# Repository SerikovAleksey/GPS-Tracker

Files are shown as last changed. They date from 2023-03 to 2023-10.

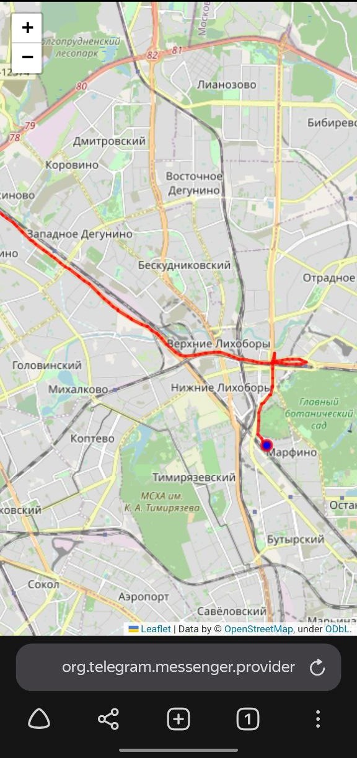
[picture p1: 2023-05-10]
Инструкция/7.jpg

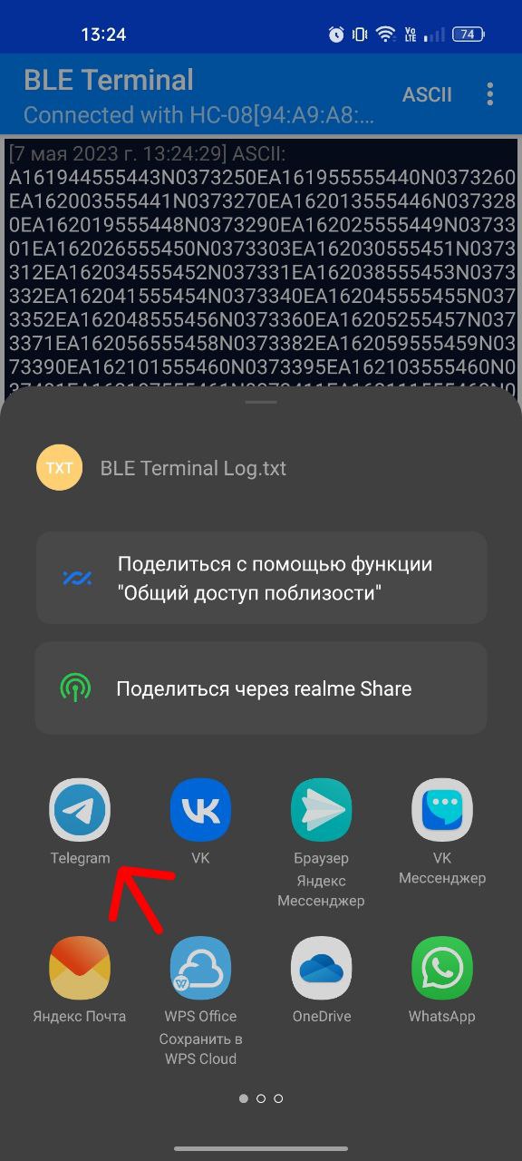
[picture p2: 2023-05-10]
Инструкция/3.jpg

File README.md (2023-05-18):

# GPS-Tracker
Репозиторий с проектом по курсу ПФТиКМИ студентов 2 курса ФАКТ:
- [Бунакова Егора](https://vk.com/egobun)
- [Серикова Алексея](https://vk.com/lehand_man)
- [Потапова Сергея](https://vk.com/keys619)

Данный проект основан на давнем желание Егора о создании своими руками GPS устройствва, с помощью которого можно посмотреть свой путь во время активного времяпрепровождения в походе, на рыбалке, на охоте и т.п.
Данный девайс должен удовлетворять нескольким требованием таким как:
- интуитивное управление
- быстрая передача данных на телефон
- долгое время работы без подзаряда

Ознакомиться с презентацией защиты плана можно [тут](https://github.com/SerikovAleksey/GPS-Tracer/blob/main/GPS%20Tracer.pptx).

А также получить подробную версию плана можно [тут](https://github.com/SerikovAleksey/GPS-Tracer/blob/main/PLAN.md).

Презентацию с защитой макета можно посмотреть [тут](https://github.com/SerikovAleksey/GPS-Tracker/blob/main/maket_defence.pptx).

Инструкцию по использованию GPS TRACKER можно посмотреть [тут](https://github.com/SerikovAleksey/GPS-Tracker/blob/main/Инструкция/Инструкция.pdf).

Протоколы испытаний можно посмотреть [тут](https://github.com/SerikovAleksey/GPS-Tracker/tree/main/Испытания).

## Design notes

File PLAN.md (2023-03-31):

# План проекта GPS Tracer 

1. Проблема 
2. Вариант решения
3. Компоненты 
4. Задачи

## Проблема 

Основным устройством, которое есть у всех, является телефон, на который можно 
установить различные приложения для отслеживания своего местоположения, но зачастую это 
становится невозможным ввиду погодных условий и других обстоятельств. Поэтому есть 
портативные устройства, выполняющие такие же задачи, но в суровых условиях. И основная 
проблема данных девайсов в их цене, она колеблется от 5 до нескольких десятков тыс. 
рублей.

## Вариант решения

С нашей стороны мы можем создать устройство способное выполнять функцию получения
данных со спутников, но за гораздо меньшую стоимость. Еще нужно для телефона написать 
приложение, где можно уже посмотреть на карте трек пройденного маршрута.

## Необходимые компоненты

| Название | Стоимость, ₽ |
|---|---|
| Приёмник GPS | ~350 |
| Модуль Bluetooth  | ~350 |
| Модуль зарядки аккумулятора| ~100|
| STM32F103C8T6 | ~150 |
| Кнопки | ~100 |
| Аккумулятор | ~500 |
| ИТОГО | ~1500 |

Цены на модули взяты с сайта [Амперо](https://ampero.ru/)

## Задачи

Перед нами встает ряд нескольких задач, которые нужно решить:
- Собрать макет устройства, т.е спаять все компоненты, и проверить его работоспособность.
- Разработать и распечатать на 3D принтере корпус.
- Создать приложение на телефон, в котором с помощью Bluetooth можно получить данные 
с устройства и визуализировать трек на карте.
- Написать инструкцию по эксплуатации.
- Провести независимые тестирования.

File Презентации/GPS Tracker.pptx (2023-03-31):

## GPS TracKer

Авторы:
Бунаков Егор
Потапов сергей
Сериков алексей

## Проблема

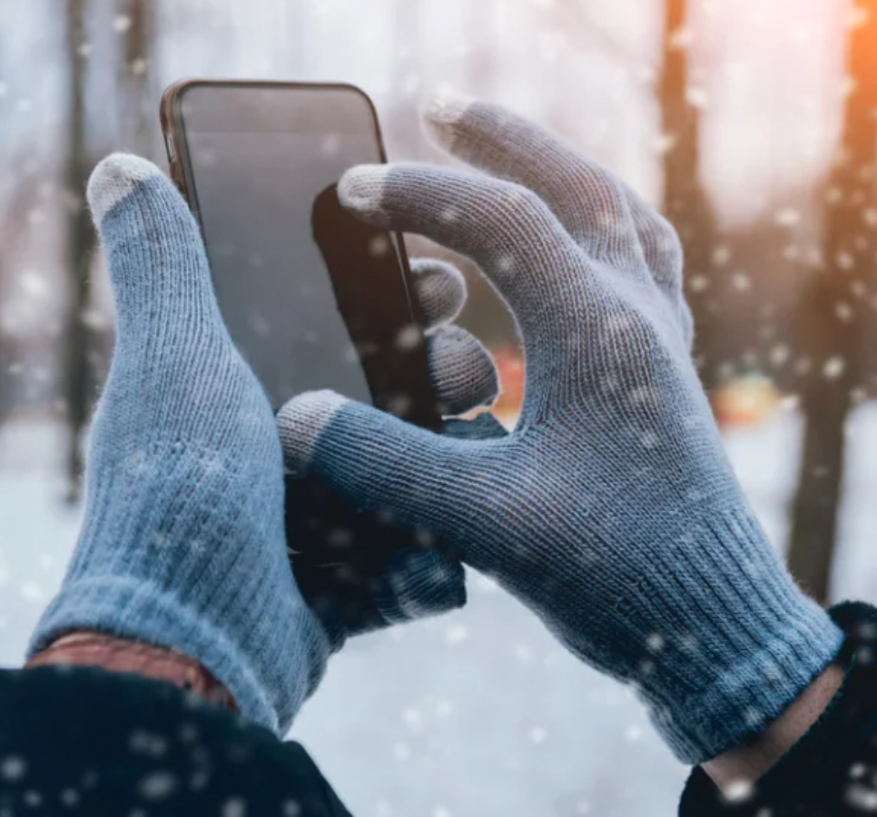
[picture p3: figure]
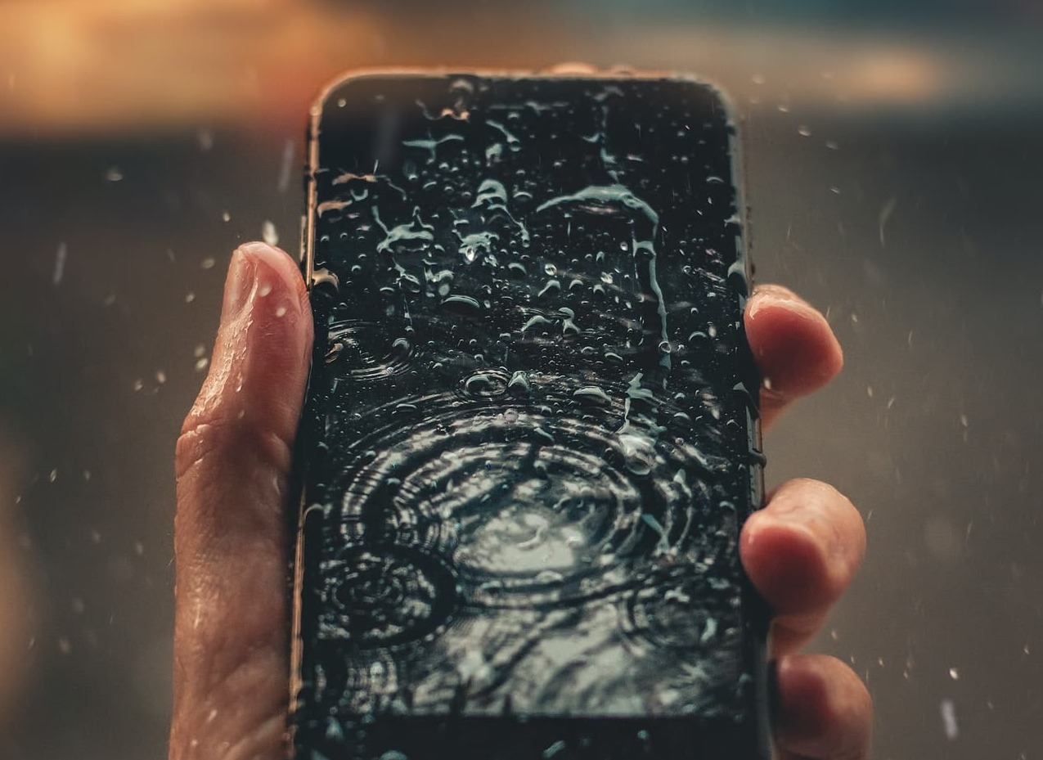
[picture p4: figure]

- Использование телефона в суровых условиях.
- Потеря связи.
- Дорогие аналоги.

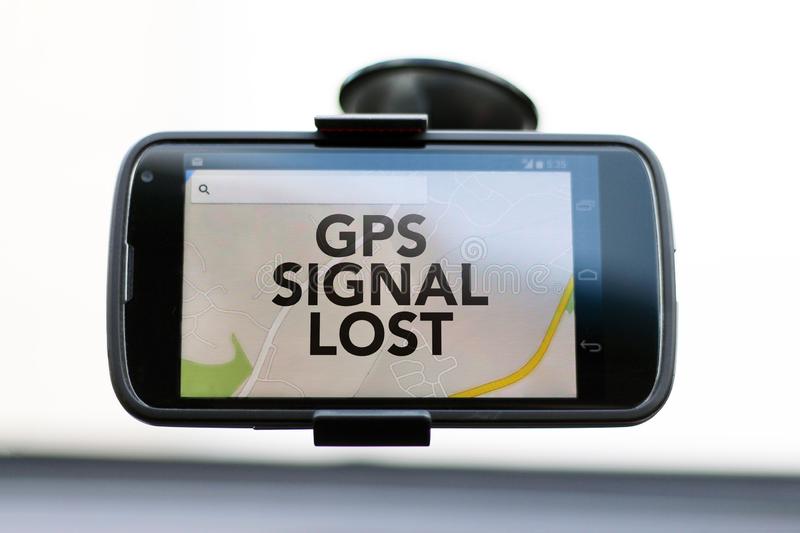
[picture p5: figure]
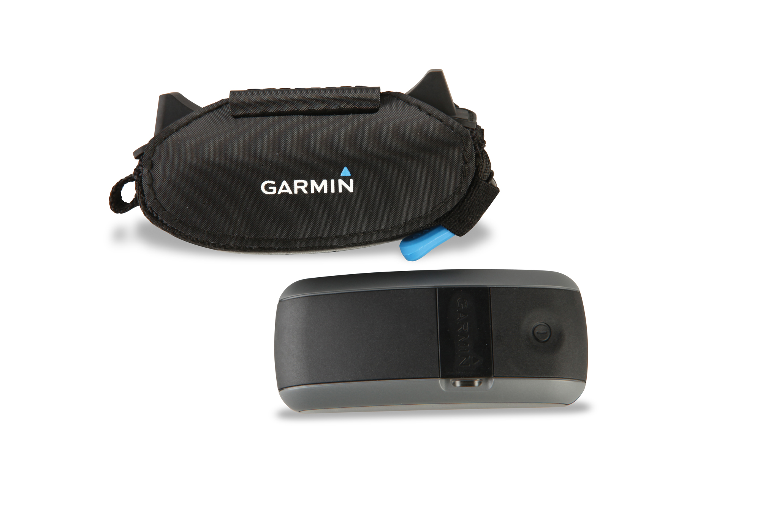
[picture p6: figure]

## Вариант решения

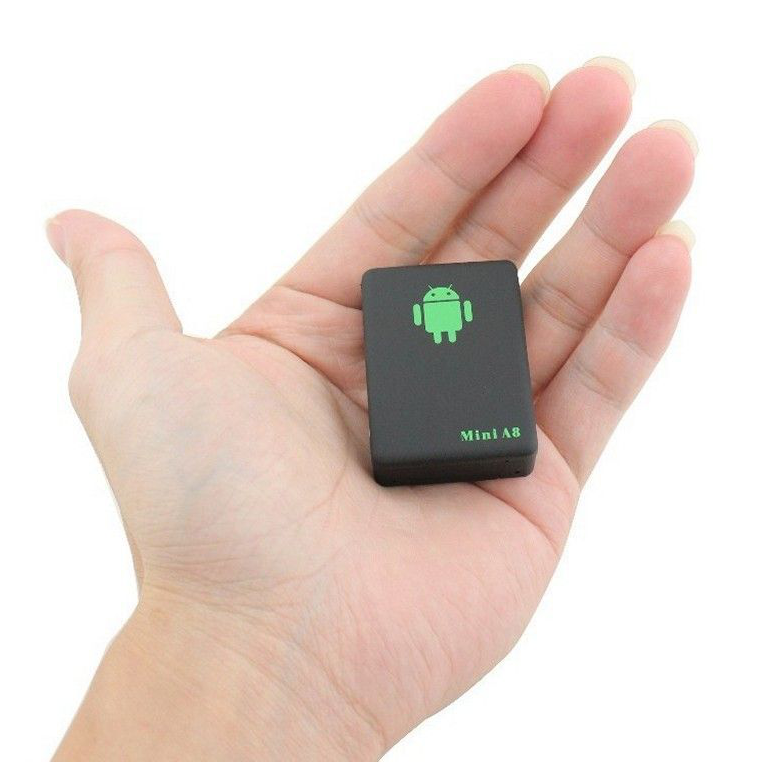
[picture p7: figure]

- Простое, компактное устройство.
- Надежные компоненты.
- Интуитивное использование.

## Задачи

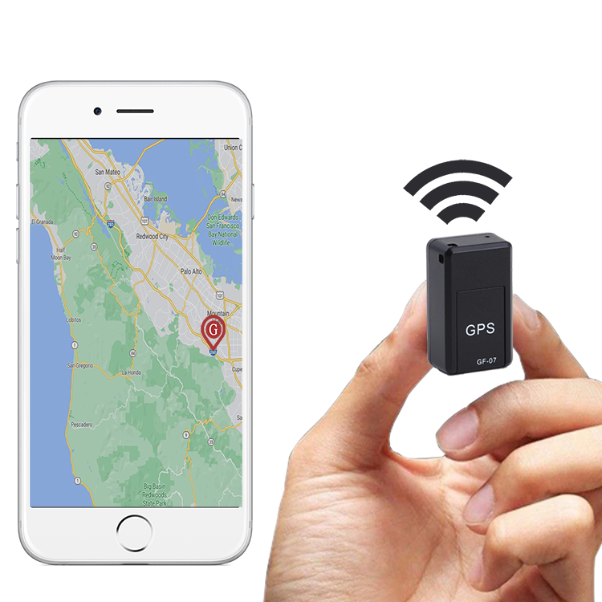
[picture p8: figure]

- Создать автономное GPS устройство.
- Сделать приложение на телефон.

## Начальные условия

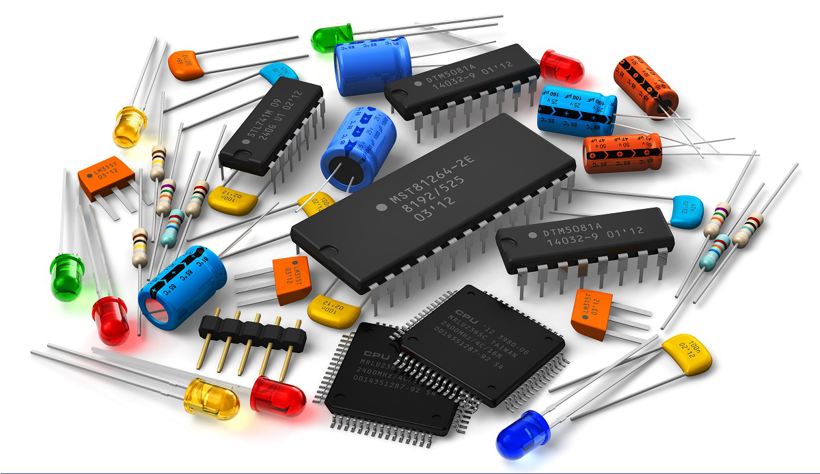
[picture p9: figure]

- РТ компоненты.
- 3D печать.
- Паяльные принадлежности.

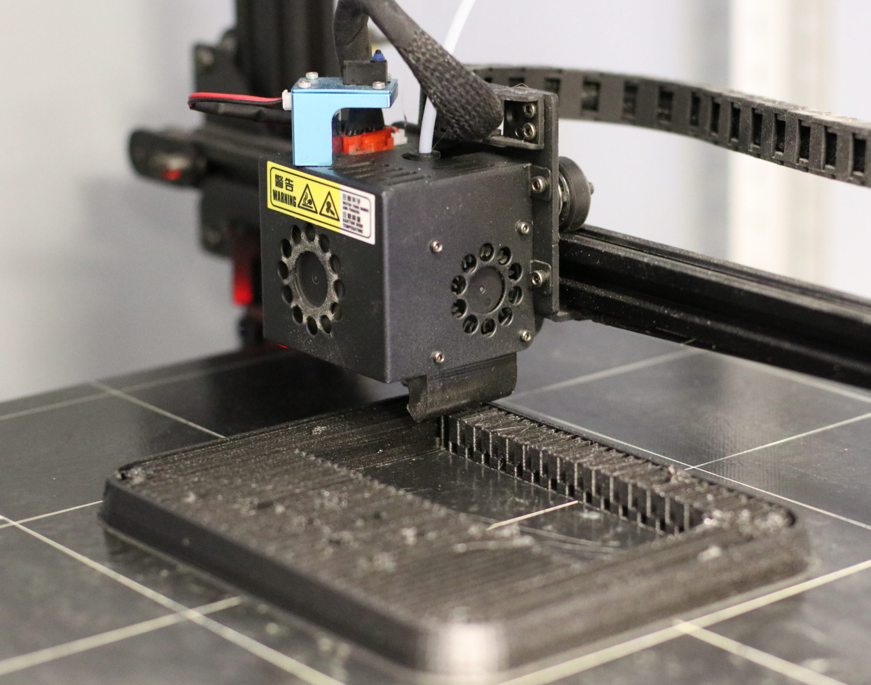
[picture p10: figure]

## Компоненты

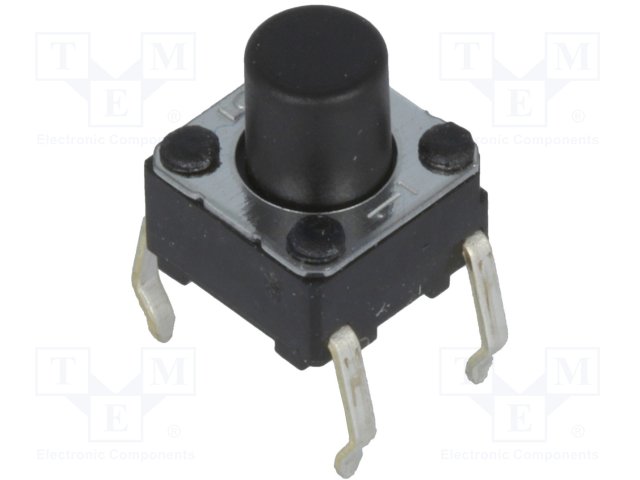
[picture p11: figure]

- STM32F103C8T6.
- GPS модуль.
- Bluetooth модуль.
- Кнопки
- Аккумулятор.

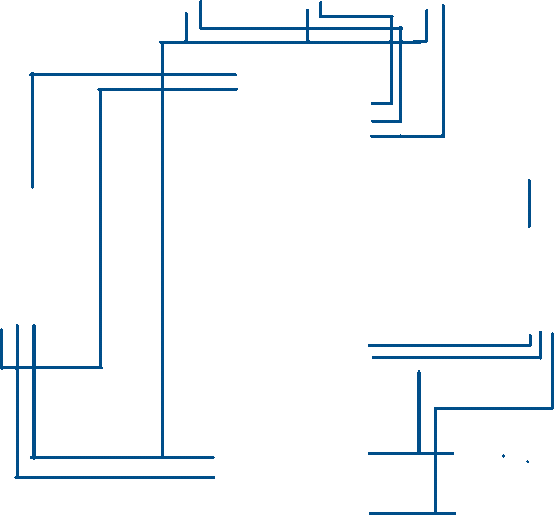
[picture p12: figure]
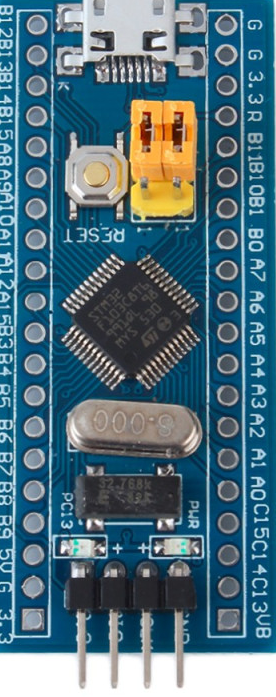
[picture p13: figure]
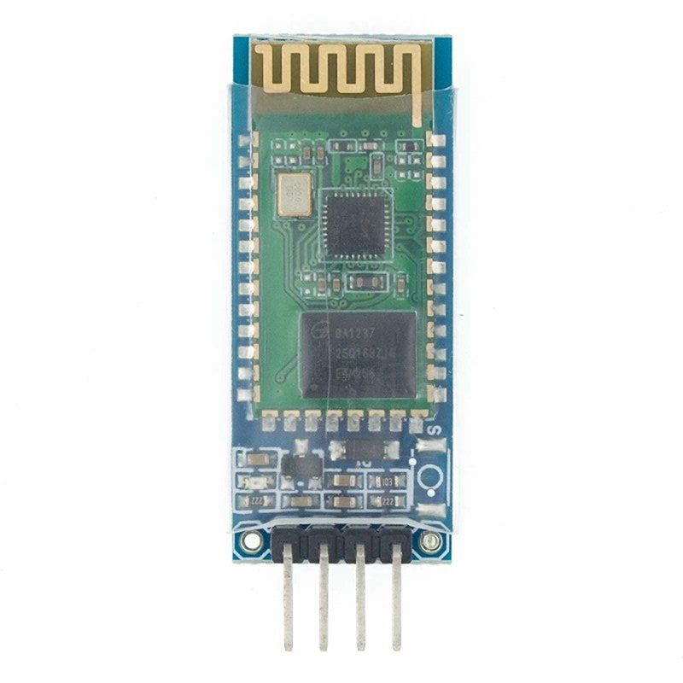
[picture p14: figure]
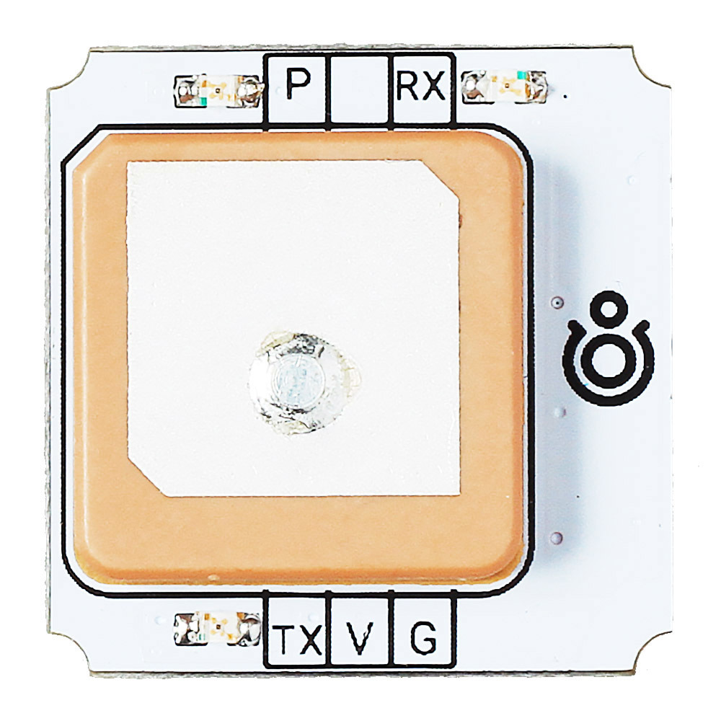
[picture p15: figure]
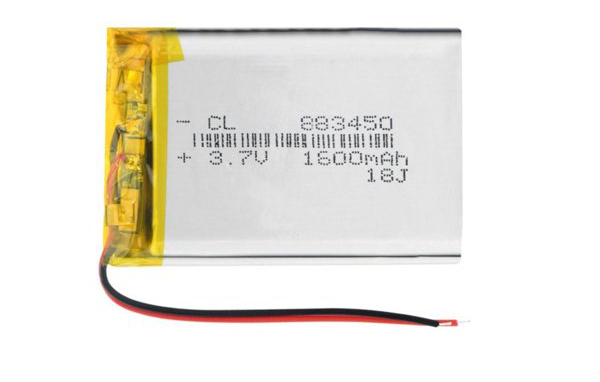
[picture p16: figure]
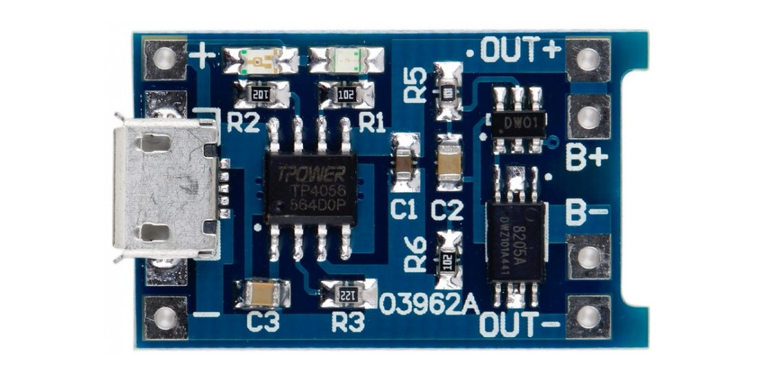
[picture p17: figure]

## Контакты

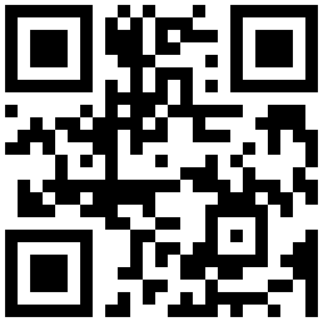
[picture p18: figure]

- Telegram канал нашего проекта

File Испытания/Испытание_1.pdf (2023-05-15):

Федеральное государственное автономное образовательное учреждение высшего образования «Московский физико-технический институт (национальный исследовательский университет)»

________________________________________________________________________________

### ПРОТОКОЛ ИСПЫТАНИЙ

№ 001/23

от «1» мая 2023 г.

1. Объект испытания: GPS TRACKER
2. Цель испытания: проверка соответствия объекта испытания требованиям пунктов 2.2, 2.3, 2.5 технического задания:

-2.2(Инструментальная погрешность навигационных определений),

-2.3(Время получения первых навигационных определений),

-2.5(Потребляемая мощность).

3. Дата начала испытания: 2 мая 2023 г.
4. Дата окончания испытания: 4 мая 2023 г.
5. Место проведения испытания: г. Москва

6. Результаты испытания
Наименование параметра | Единицы измерения | Методика испытаний | Требования к параметру | Измеренное значение
Инструментальная погрешность навигационных определений | М(метр) | Запись трека в течении 2 часов | ± 5м | ± 8м
Время получения первых навигационных определений | С(секунда) | Фиксирование времени получения навигационных определений | 5с (горячий старт) 35с (теплый старт) 50с (холодный старт) | 4с (горячий старт) 33с (теплый старт) 45с (холодный старт)
Потребляемая мощность | Вт (Ватт) | Фиксирование времени работы устройства | 0.2Вт | 0.26Вт
7. Замечания и рекомендации:

Погрешность навигационных определений выше, чем заявлена, в городе точность невысокая.

При холодном старте необходимо стоять на месте, иначе время получения первых навигационных определений выше.

Время работы устройства меньше заявленного.

8. Выводы:
8.1. Объект испытания GPS TRACKER соответствует требованиям пункта 2.3 технического задания.
8.2. Объект испытания GPS TRACKER не соответствует требованиям пунктов 2.2 и 2.5 технического задания.

Испытание проводили:

Должность | И.О. Фамилия | Подпись
Тестировщик | А.М. Галактионова

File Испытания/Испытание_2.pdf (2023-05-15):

Федеральное государственное автономное образовательное учреждение высшего образования «Московский физико-технический институт (национальный исследовательский университет)»

________________________________________________________________________________

### ПРОТОКОЛ ИСПЫТАНИЙ

№ 002/23

от «10» мая 2023 г.

1. Объект испытания: GPS TRACKER
2. Цель испытания: проверка соответствия объекта испытания требованиям пунктов 2.2, 2.3, 2.5 технического задания:

-2.2(Инструментальная погрешность навигационных определений),

-2.3(Время получения первых навигационных определений),

-2.5(Потребляемая мощность).

3. Дата начала испытания: 11 мая 2023 г.
4. Дата окончания испытания: 12 мая 2023 г.
5. Место проведения испытания: г. Москва

6. Результаты испытания
Наименование параметра | Единицы измерения | Методика испытаний | Требования к параметру | Измеренное значение
Инструментальная погрешность навигационных определений | М(метр) | Запись трека в течении 2 часов | ± 8м | ± 7м
Время получения первых навигационных определений | С(секунда) | Фиксирование времени получения навигационных определений | 5с (горячий старт) 35с (теплый старт) 50с (холодный старт) | 3с (горячий старт) 31с (теплый старт) 49с (холодный старт)
Потребляемая мощность | Вт (Ватт) | Фиксирование времени работы устройства | 0.26Вт | 0.24Вт
7. Замечания и рекомендации:

Точность полученных данных лежит в пределах погрешности.

Мощность потребления соответствует заявленной.

Время получение навигационных данных укладывается в заявленное.

8. Выводы:
8.1. Объект испытания GPS TRACKER соответствует требованиям пункта 2.2, 2.3, 2.5 технического задания.

Испытание проводили:

Должность | И.О. Фамилия | Подпись
Тестировщик | Сериков В.Р

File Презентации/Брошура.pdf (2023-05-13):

# GPS TRACKER

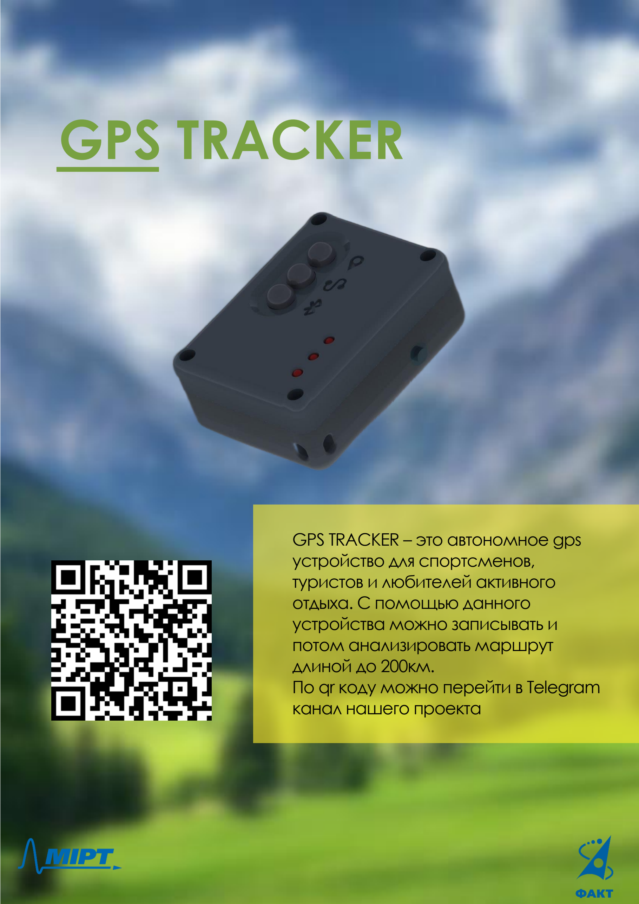
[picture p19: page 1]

GPS TRACKER – это автономное gps устройство для спортсменов, туристов и любителей активного отдыха. С помощью данного
устройства можно записывать и потом анализировать маршрут длиной до 200км.
По qr коду можно перейти в Telegram канал нашего проекта

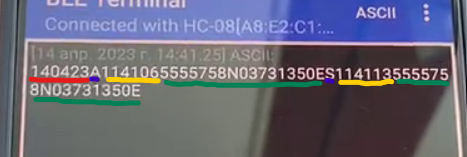
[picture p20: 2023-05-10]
Фото/data.png

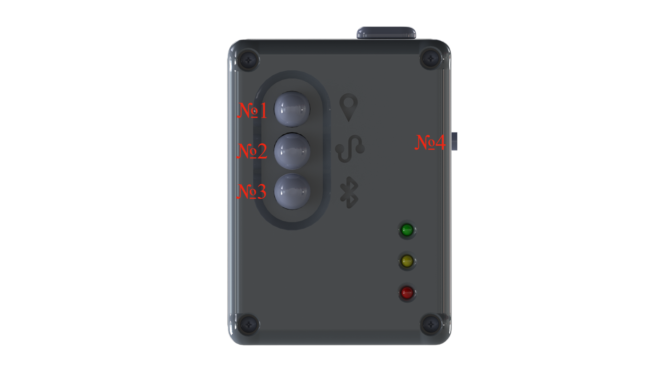
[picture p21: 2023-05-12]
Инструкция/кнопки.png

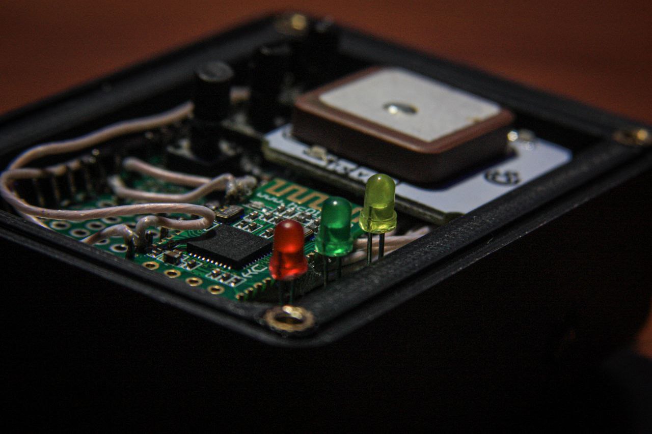
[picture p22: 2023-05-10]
Фото/трекер_1.jpg

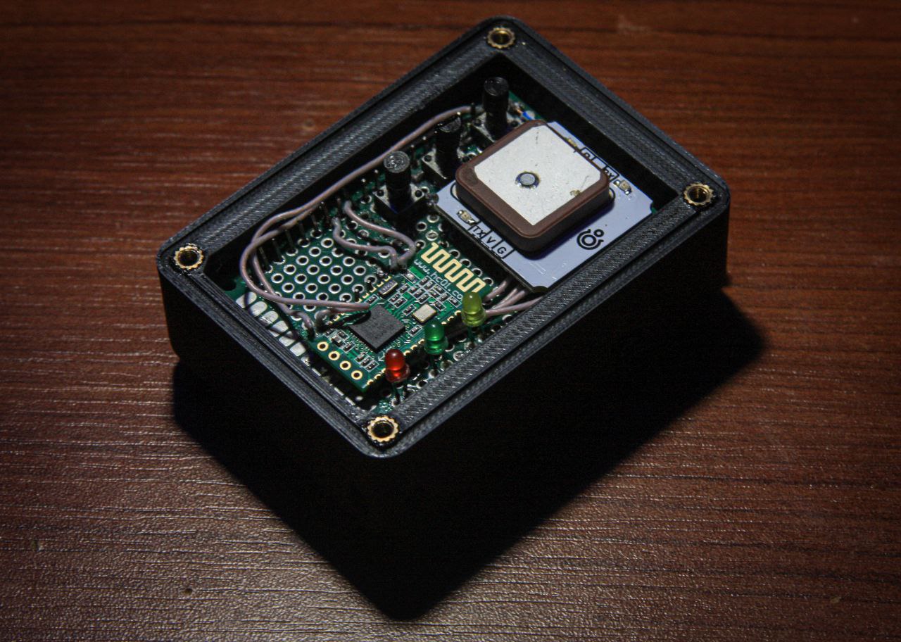
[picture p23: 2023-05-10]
Фото/трекер_2.jpg

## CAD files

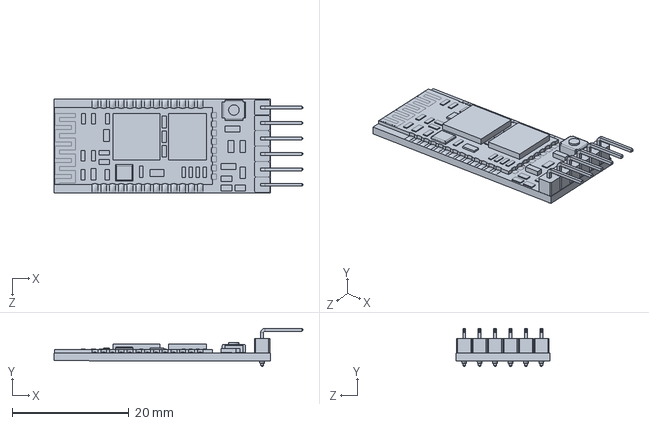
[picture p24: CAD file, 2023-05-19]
Чертежи/HC-05.SLDPRT
42.6 x 6.55 x 16.0 mm

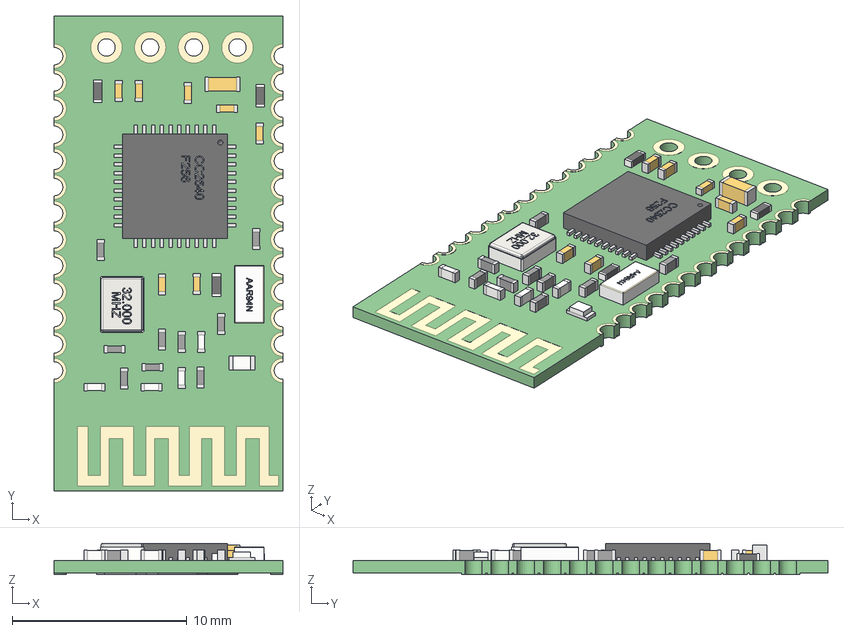
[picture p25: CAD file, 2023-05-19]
Чертежи/hc-08 .step
13.1 x 27.2 x 1.80 mm
CC2540
resistencia x 3
Capacitor 12x04x06 x 7
Capacitor 17x08x09
Capacitor 12x04x06 gris x 9
Capacitor 12x04x06 Blanco x 4
AAR94N
Cristal 32000 mhz
Led azul
COHETE cdmx

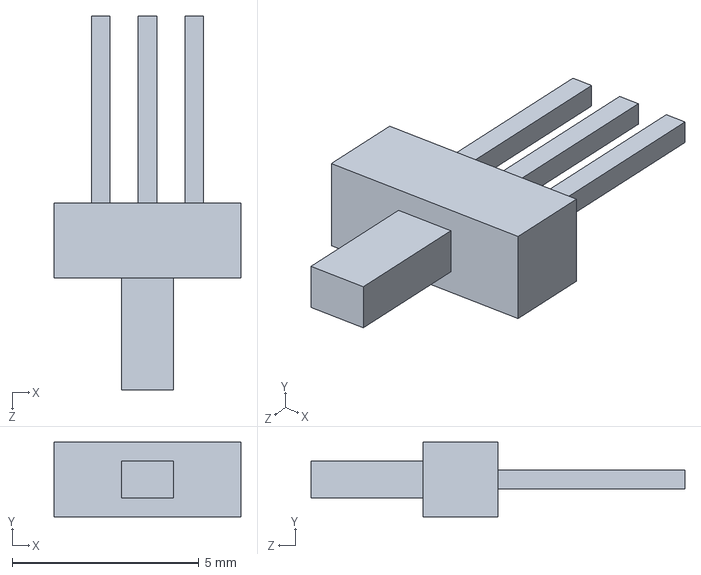
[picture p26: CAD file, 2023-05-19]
Чертежи/Переключатель.SLDPRT
5.00 x 2.00 x 10.0 mm

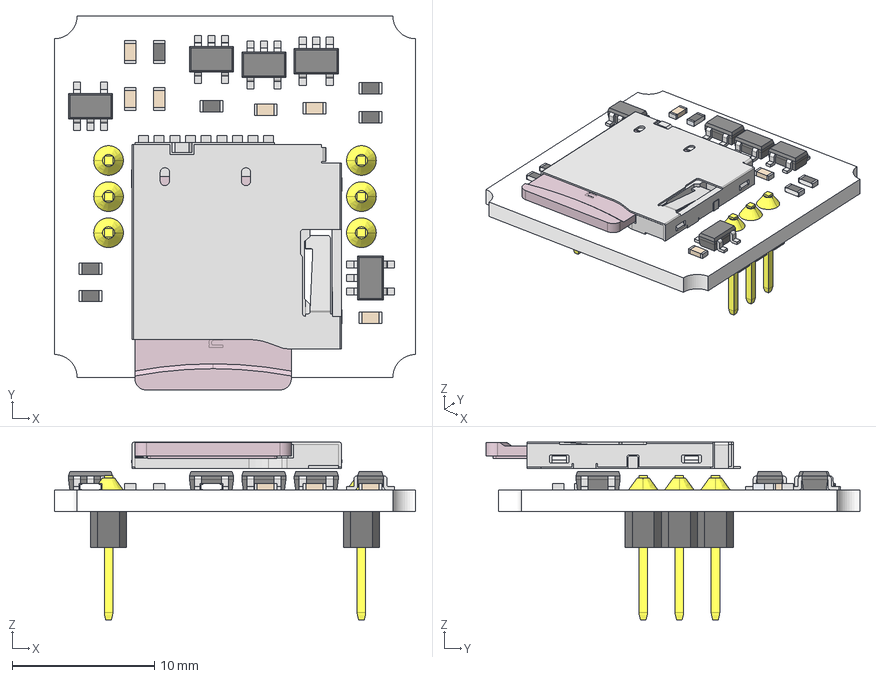
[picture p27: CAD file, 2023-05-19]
Чертежи/Troyka SD card.stp
25.4 x 26.3 x 12.5 mm
C0603 x 6
SOT23-5 Geometry x 5
leg x 25
R0603 x 6
pcbgroup
PLS 1x1_soldered Geometry x 6
Micro SD
slot

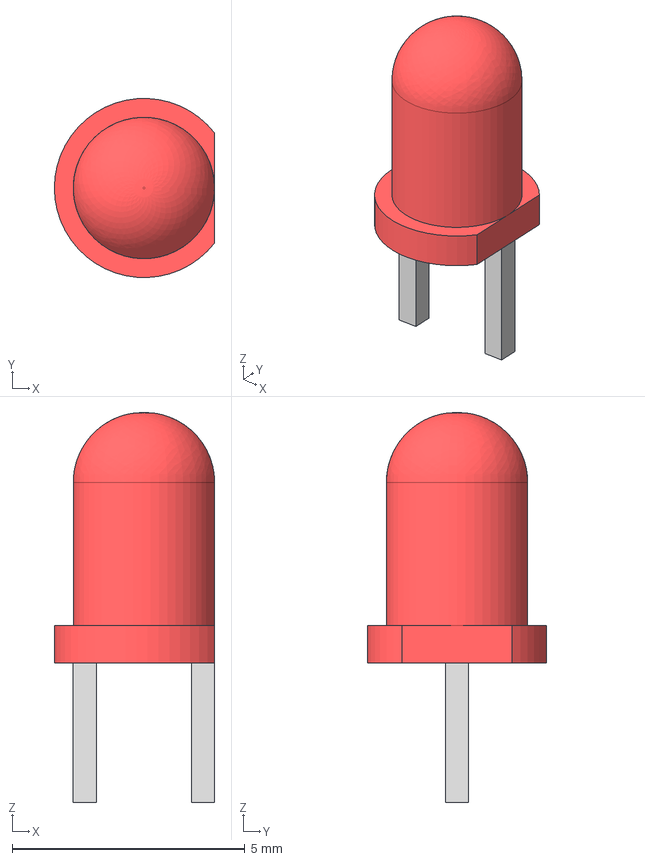
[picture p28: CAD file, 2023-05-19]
Чертежи/LED 3mm Red 3mm Leads.step
3.45 x 3.85 x 8.38 mm
LEDBody
Lead1Body
Lead2Body

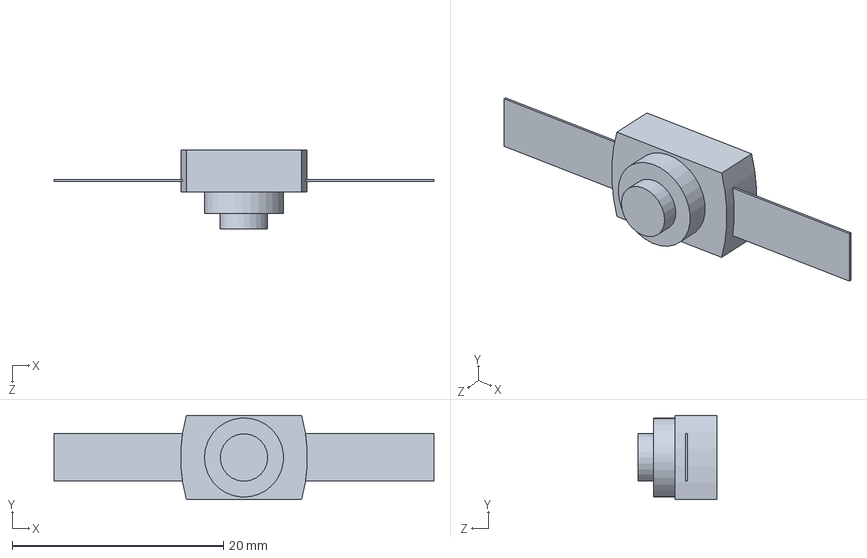
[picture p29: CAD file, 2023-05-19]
Чертежи/кнопка включения.SLDPRT
36.0 x 8.00 x 7.50 mm

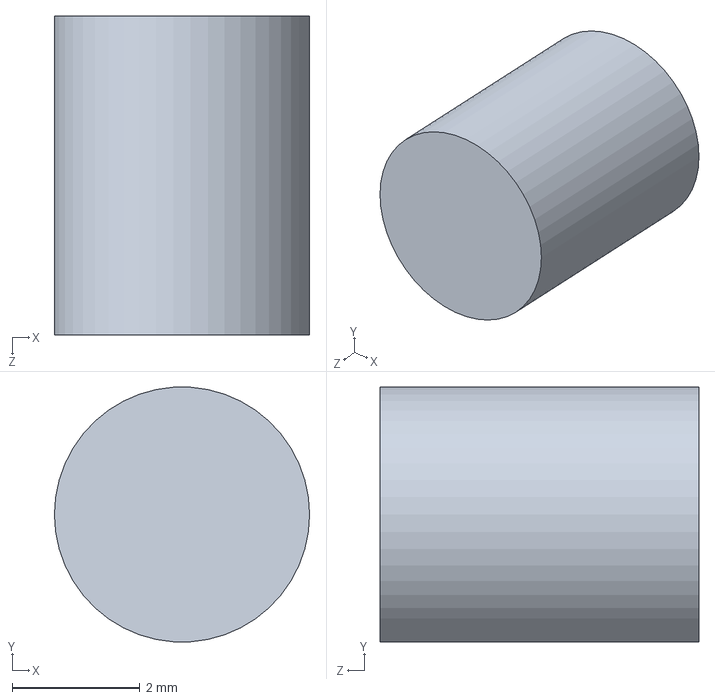
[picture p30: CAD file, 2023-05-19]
Чертежи/удлинитель кнопки.SLDPRT
4.00 x 3.99 x 5.00 mm

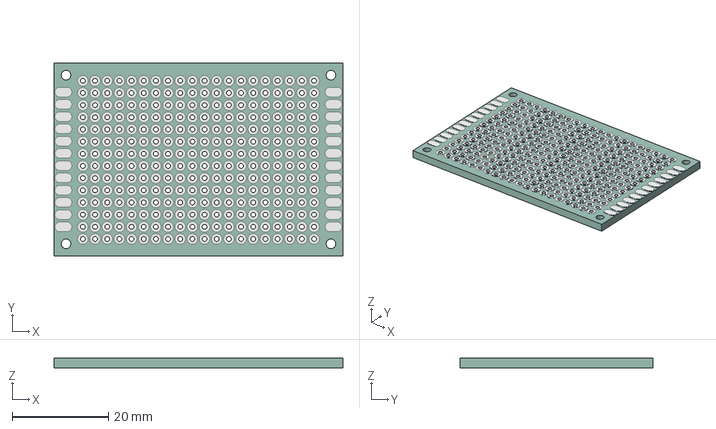
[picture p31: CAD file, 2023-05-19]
Чертежи/pcb_proto_board(40x60) .step
60.0 x 40.0 x 2.10 mm

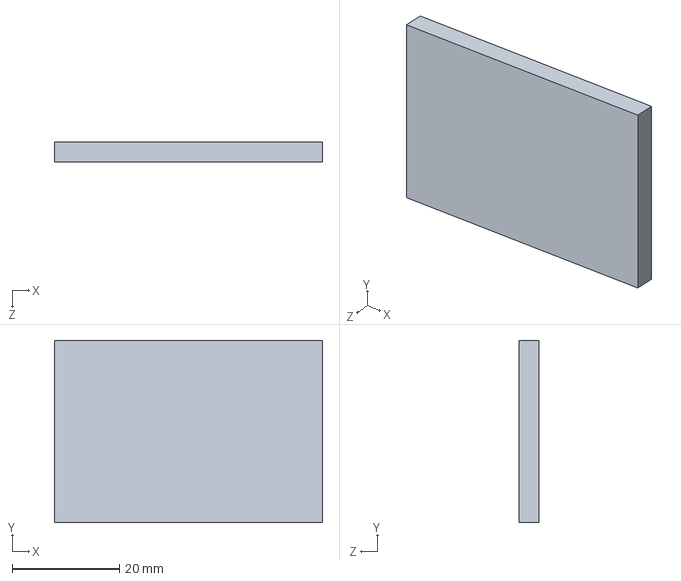
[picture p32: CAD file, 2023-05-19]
Чертежи/аккумулятор.SLDPRT
50.0 x 34.0 x 3.80 mm

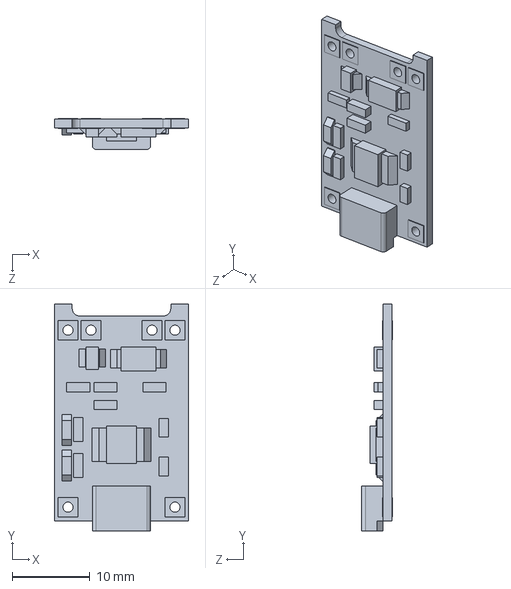
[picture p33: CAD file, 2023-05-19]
Чертежи/tp4056 micro usb 18650 charger.SLDPRT
17.3 x 29.2 x 4.00 mm

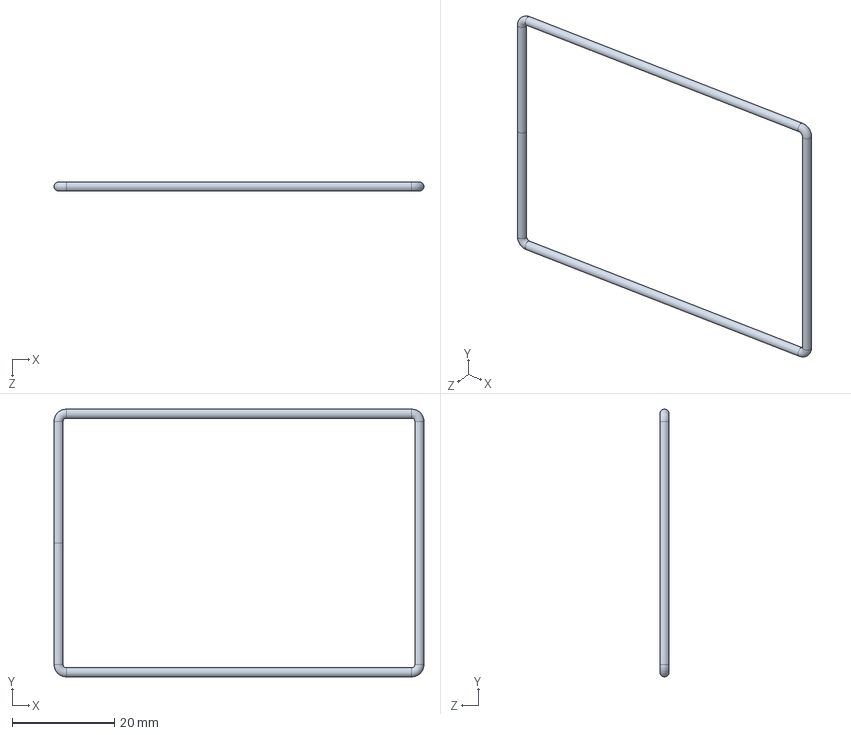
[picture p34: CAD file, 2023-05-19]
Чертежи/прокладка.SLDPRT
72.4 x 52.4 x 1.80 mm

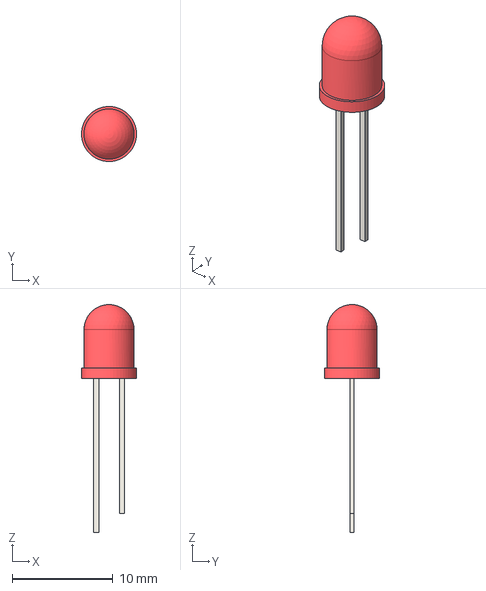
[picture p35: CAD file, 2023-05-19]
Чертежи/LED 3mm (Red).step
5.46 x 5.46 x 22.6 mm

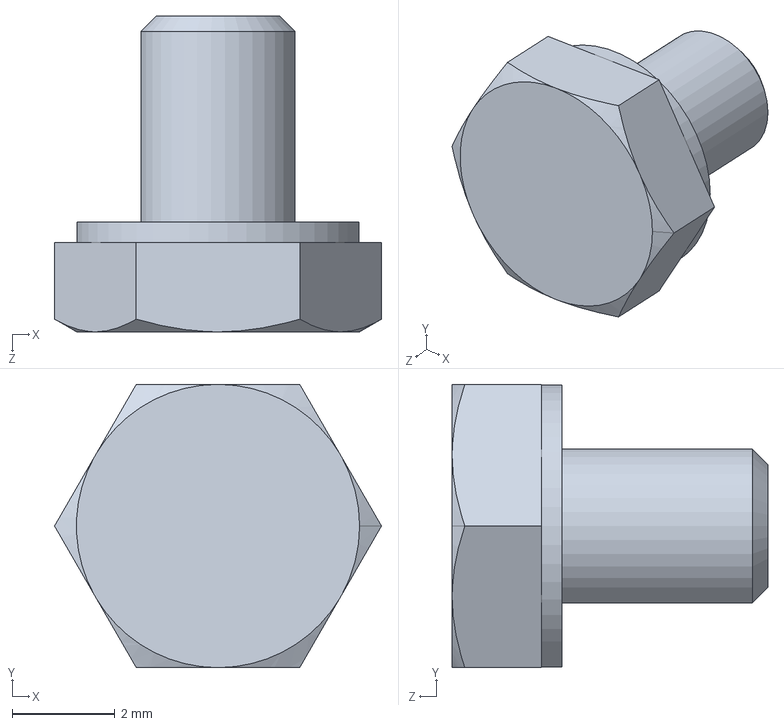
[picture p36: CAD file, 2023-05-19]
Чертежи/hexagonal_head_bolt_M3x04.step.SLDPRT
6.35 x 5.50 x 6.13 mm

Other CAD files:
Чертежи/Stiftleiste, RM 2,54 mm - 6-3 mm, gerade - 1 x 20 - schwarz.SLDPRT

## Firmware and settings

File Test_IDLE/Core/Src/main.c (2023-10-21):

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
/* Includes ------------------------------------------------------------------*/
#include "main.h"

/* USER CODE BEGIN Includes */
#include <stdio.h>
#include <string.h>
#include "nmea.h"
#include "button.h"
#include "flash.h"
#include <stdlib.h>
/* USER CODE END Includes */

/* USER CODE BEGIN PD */
#define rx_buffer_size 1000 // received buffer size
/* USER CODE END PD */

TIM_HandleTypeDef htim2;

UART_HandleTypeDef huart1;
UART_HandleTypeDef huart2;

/* USER CODE BEGIN PV */
uint8_t rx_buffer[rx_buffer_size] = {0, }; //received buffer

uint8_t push_on_off = 0; // responsible for pressing the button to start recording coordinates
uint8_t push_transmit = 0; // responsible for pressing the button to transmit recording coordinates
uint8_t push_make_point = 0; //responsible for pressing the button to make special coordinates

//uint8_t check_power = 0;
uint8_t check_capacity = 0; //responsible for flash-memory recording


/* USER CODE END PV */

void SystemClock_Config(void);
static void MX_GPIO_Init(void);
static void MX_USART1_UART_Init(void);
static void MX_USART2_UART_Init(void);
static void MX_TIM2_Init(void);
/* USER CODE BEGIN 0 */



void HAL_UART_IDLE_Callback(UART_HandleTypeDef *huart) {
	if (huart == &huart1) {
		__HAL_UART_DISABLE_IT(&huart1, UART_IT_IDLE);


		HAL_UART_AbortReceive_IT(&huart1);
		__HAL_UART_CLEAR_IDLEFLAG(&huart1);
		__HAL_UART_ENABLE_IT(&huart1, UART_IT_IDLE);
		HAL_UART_Receive_IT(&huart1, (uint8_t*)rx_buffer, rx_buffer_size);
	}
}

void HAL_UART_RxCpltCallback(UART_HandleTypeDef *huart) {
	if (huart == &huart1) {
		__HAL_UART_DISABLE_IT(&huart1, UART_IT_IDLE);

		HAL_UART_AbortReceive_IT(&huart1);
		__HAL_UART_CLEAR_IDLEFLAG(&huart1);
		__HAL_UART_ENABLE_IT(&huart1, UART_IT_IDLE);
		HAL_UART_Receive_IT(&huart1, (uint8_t*)rx_buffer, rx_buffer_size);
	}
}

void HAL_GPIO_EXTI_Callback(uint16_t GPIO_Pin)
{
	uint16_t t0 = TIM2->CNT;
	if (GPIO_Pin == BUT_ON_OFF) // on or off record track
	{
		if (Read_Button_Time_Push(GPIO_Pin, t0) < 200) push_on_off = 1;
		
		if (Read_Button_Time_Push(GPIO_Pin, t0) > 1000) push_on_off = 2;
	}
	
	if (GPIO_Pin == BUT_MAKE_POINT) // make a point
	{
		if (Read_Button_Time_Push(GPIO_Pin, t0) < 400) push_make_point = 1;
	}
	
	if (GPIO_Pin == BUT_TRANSMIT_DATA) // send data
	{
		if (Read_Button_Time_Push(GPIO_Pin, t0) < 400) push_transmit = 1;
	}
	
}

/* USER CODE END 0 */

/**
  * @brief  The application entry point.
  * @retval int
  */
int main(void)
{
  /* MCU Configuration--------------------------------------------------------*/

  /* Reset of all peripherals, Initializes the Flash interface and the Systick. */
  HAL_Init();

  /* USER CODE BEGIN Init */
	

	//FLASH_Read(ADDR_FLASH_PAGE_127, b);
  /* USER CODE END Init */

  /* Configure the system clock */
  SystemClock_Config();

  /* Initialize all configured peripherals */
  MX_GPIO_Init();
  MX_USART1_UART_Init();
  MX_USART2_UART_Init();
  MX_TIM2_Init();
  /* Infinite loop */
  /* USER CODE BEGIN WHILE */
  while (1)
  {
		
		uint8_t *buffer = get_transmit_buf().buf;
		uint16_t size = get_transmit_buf().size;
		uint16_t u16_size = 0;
		
		if ((size / 2) % 2 != 0)	
		{
			u16_size = size / 2 + 1;
		}
		else u16_size = size / 2;
		
		
		if (check_valid_data(rx_buffer) == -1 && !check_capacity) 
		{
			HAL_GPIO_WritePin(GPIOB, GPIO_PIN_9, GPIO_PIN_SET);
			Delay(300);
			HAL_GPIO_WritePin(GPIOB, GPIO_PIN_9, GPIO_PIN_RESET);
		}
		else if (check_valid_data(rx_buffer) && !push_on_off && !check_capacity)
		{
			HAL_GPIO_WritePin(GPIOB, GPIO_PIN_5, GPIO_PIN_SET);
			Delay(300);
			HAL_GPIO_WritePin(GPIOB, GPIO_PIN_5, GPIO_PIN_RESET);
		}
		
		
		if (size >= 980 && size < 1010)
		{
			Save_Data(buf_u8_to_u16(buffer, size), u16_size + 1);
			Save_Data(&amount_lists, 1);
			set_ind_c(0);
			set_ind_t(0);
			amount_lists++;
		} // save data on one page flash-memory
		
		if (push_on_off == 1 && !push_make_point)
		{
			nmea_handler(rx_buffer, AVERAGE);
			HAL_GPIO_WritePin(GPIOB, GPIO_PIN_5, GPIO_PIN_SET);
		} // start receive data
		
		if (push_on_off == 1 && push_make_point) 
		{
			nmea_handler(rx_buffer, SPECIAL);
			push_make_point = 0;
			HAL_GPIO_WritePin(GPIOB, GPIO_PIN_4, GPIO_PIN_SET);
		} // make a special point
		Delay(300);
		HAL_GPIO_WritePin(GPIOB, GPIO_PIN_4, GPIO_PIN_RESET);
		
		
		if (push_on_off == 2) 
		{
			Save_Data(buf_u8_to_u16(buffer, size), u16_size + 1);
			Save_Data(&amount_lists, 1);
			push_on_off = 0;
			set_ind_c(0);
			set_ind_t(0);
			amount_lists++;
		} //stop receive and save data 
		
		if (push_on_off == 0) 
		{
			HAL_GPIO_WritePin(GPIOB, GPIO_PIN_5, GPIO_PIN_RESET);
		}
		
		if (push_transmit)
		{
			uint16_t lists = 0;
			if ((*((uint32_t*)(ADDR_AMOUNT_PAGES))) == 0xFF) lists = 0;
			else lists = (*((uint32_t*)(ADDR_AMOUNT_PAGES)));
			for (uint16_t i = 0; i < lists; i++)
			{
				uint32_t add = ((uint32_t)(ADDR_FLASH_PAGE_126 -((uint32_t)(0x0000400 * (uint32_t)i))));
				uint16_t len = (*((uint32_t*)(ADDR_FLASH_PAGE_126 -((uint32_t)(0x0000400 * (uint32_t)i)))));
				transmit_data(buf_u16_to_u8(Read_Data(add, len), len), len * 2);
			}
			HAL_GPIO_WritePin(GPIOB, GPIO_PIN_4, GPIO_PIN_SET);
			Delay(1000);
			HAL_GPIO_WritePin(GPIOB, GPIO_PIN_4, GPIO_PIN_RESET);
			push_transmit = 0;
		}
		
		if (address_list_now == ((uint32_t)0x08007800))
		{
			check_capacity = 1;
			push_on_off = 0;
		} //check flash-memory capacity
		
		if (check_capacity)
		{
				HAL_GPIO_WritePin(GPIOB, GPIO_PIN_9, GPIO_PIN_SET);
		}
		
    /* USER CODE END WHILE */

}

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


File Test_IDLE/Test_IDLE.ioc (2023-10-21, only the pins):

Mcu.UserName=STM32F103C8Tx
PA10.Signal=GPXTI10
PA11.Signal=GPXTI11
PA13.Signal=SYS_JTMS-SWDIO
PA14.Signal=SYS_JTCK-SWCLK
PA2.Signal=USART2_TX
PA3.Signal=USART2_RX
PA9.Signal=GPXTI9
PB3.Signal=SYS_JTDO-TRACESWO
PB4.Signal=GPIO_Output
PB5.Signal=GPIO_Output
PB6.Signal=USART1_TX
PB7.Signal=USART1_RX
PB9.Signal=GPIO_Output

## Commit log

2023-04-26 обновил прошивку (добавил светодиоды)
2023-04-30 исправил ошибки с отправкой данных по BLUETOOTH
    [main.c, nmea.c]
2023-05-01 убрал ошибки с записью больших пакетов данных
2023-05-10 добавил инструкцию
2023-05-10 Добавил презентацию, фото
2023-05-11 обновил инструкцию
2023-05-11 обновил презентацию и добавил брошуру
2023-05-13 обновил презентацию
2023-05-13 новая презентация
2023-05-15 добавил испытания и обновил инструкцию
2023-05-19 причесал файлики
2023-05-19 Добавил код для телеграм бота
2023-05-19 обновил презу
2023-05-19 добавил чертежи
    [HC-05.SLDPRT, LED 3mm (Red).step, LED 3mm Red 3mm Leads.step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]
2023-05-19 обновил презентацию для конкурса

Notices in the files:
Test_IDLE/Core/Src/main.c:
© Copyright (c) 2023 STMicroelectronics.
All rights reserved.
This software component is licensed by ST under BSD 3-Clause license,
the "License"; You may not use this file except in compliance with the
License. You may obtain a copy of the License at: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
